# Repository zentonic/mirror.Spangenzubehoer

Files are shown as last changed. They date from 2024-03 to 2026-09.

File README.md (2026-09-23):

# Spangenzubehör

---

> https://forgejo.mueller.network/Zentonic/Spangenzubehoer.git 
> 
> Mirror: https://github.com/zentonic/mirror.Spangenzubehoer.git

---

> License: cc-by-sa-4.0 Author: holm / Christian Müller (https://mueller.network)

3D Druck Vorlage für ein Zubehördöschen mit Schiebedeckel.

Platz für
* Interdentalbürstchen
* frische Gummiringe
* Zahnspangenwachs
* Selbstklebende Spiegelfolie in einer Aussparung im Deckel

[STL-Download](STL/)

## Schiebedeckel für eigene Formen

Der Schiebedeckel steckt als eigenständige Bibliothek in
[`modules/mod_Schiebebox.scad`](modules/mod_Schiebebox.scad): Rechteck mit
Rundung oder beliebiger 2D-Umriss, Arretierung über einen einstellbaren
Hinterschnitt, Presssitz ohne Spiel (optional `spiel`). Beispiel mit
Kapselform: [`beispiele/Kapsel.scad`](beispiele/Kapsel.scad).

```openscad
include <modules/mod_Schiebebox.scad>;
P = sb_param(laenge=60, breite=25, hoehe=20, wand=2.5, rundung=4,
             deckel_d=3, hinterschnitt=0.4);
difference() { sb_koerper(P); sb_nut(P); }
translate([0, 35, 0]) sb_deckel(P);
```

Die Döschen auf [Mastodon](https://social.saarland/@holm/112083961379337663)

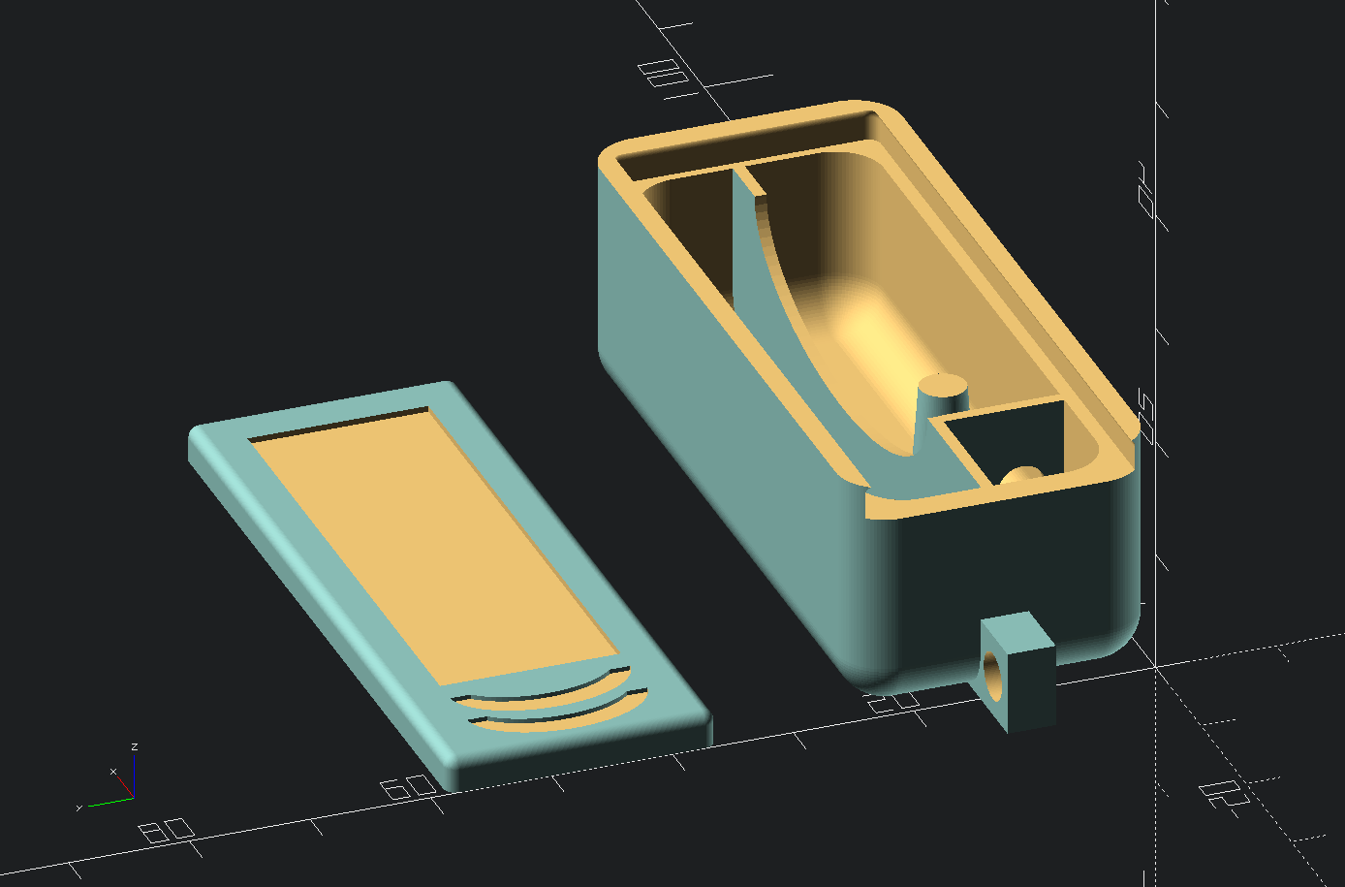
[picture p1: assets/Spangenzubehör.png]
Preview Vorschau


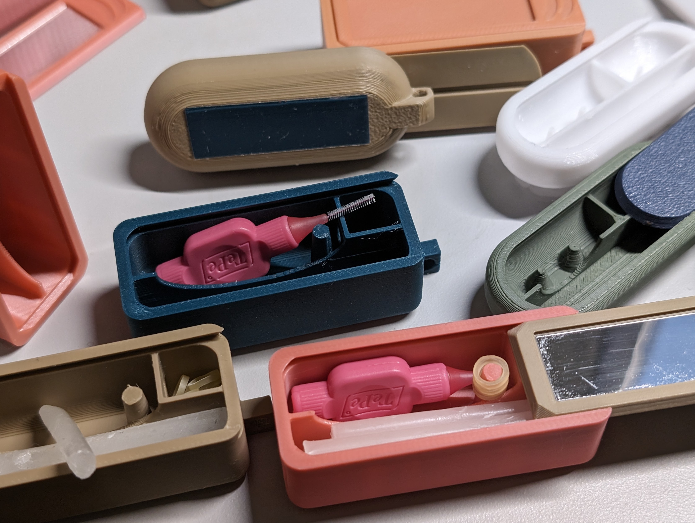
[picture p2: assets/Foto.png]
Foto Foto der Entwicklungsstufen


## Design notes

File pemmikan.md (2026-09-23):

# 🤖🥩 OpenSCAD: Spangenzubehör-Döschen mit Schiebedeckel
> Stand: 2026-09-24 01:10 — Claude.ai via Claude Code (CLI)

## STAND

ROLLE: v00 auf Opus, thinking an

- PCR 2026-09-24 01:10: Pemmikan aktuell, Issues #6–#9 und #11 geschlossen. Release-Schritt offen: `~/bin/release` würde `v2.0.0-rc.3` erzeugen (v-Präfix, ohne cliff.toml, Inhalt nur Doku seit rc.2)
- `main` = `fcb2c0d`, Tag `2.0.0-rc.2` (signiert), Forgejo-Release als Vorabversion mit STL
- **Nächster Schritt (Holm, „morgen")**: Testdruck rc.2 → bei Erfolg PCR/Release **2.0.0 final** — [#10](https://forgejo.mueller.network/Zentonic/Spangenzubehoer/issues/10)
- Branches bleiben nach Merge stehen (Holm): `fix/6-ki-layoutfix`, `fix/7-hauptsteg-zurueck`, `feat/8-schiebebox`, `feat/9-stl-rc2`
- Kein `dev`-Branch, kein CHANGELOG/cliff.toml: Merges gehen `--no-ff` direkt in `main`

## Funktion der Geometrie (Holm 2026-09-23) — Funktionsmaße, keine Kosmetik

| Teil | Funktion | Maß |
|---|---|---|
| Langes Fach (y > Hauptsteg) | Wachsstreifen, Einheitsgröße | **9,0 mm Passmaß** |
| Kurzes Fach (y < Hauptsteg, x > Quersteg) | Griff Interdentalbürste (TePe Original Pink ISO 0) | 10 mm, **bewusst lose** |
| Loch Ø4 im Quersteg | Bürstenspitze ragt in die kleine Kammer, Konus ragt ins Loch | – |
| Kleine Kammer | Zahnspangengummis | – |
| Kegel „Zyl gebraucht" | Abstreifsteg für gebrauchte Gummis (z. B. beim Essen) | Fuß bündig zur Stegseite |
| Deckelmulde | Spiegelklebefolie (Amazon) | 0,5 mm tief |
| Deckel | **Presssitz ohne Spiel**: robustes Schieben, Arretieren durch flächigen Druck | – |

TePe-Bürste, aus Fotos geschätzt (Referenz Dose + Produktbild): Länge ≈ 46 mm, Platte ≈ 13 × 16 mm, Kragen Ø ≈ 7 mm.

## Schiebedeckel-Mechanik (`modules/mod_Schiebebox.scad`, #8)

- Deckel: Platte `deckel_d` mit oben gerundeten Kanten `kante_r`, liegt auf einer Auflage `nut_tiefe` in den Seitenwänden
- Arretierung: Nutoberkante = Rand + `ueberstand`, `ueberstand = kante_r − sqrt(kante_r² − (kante_r − hinterschnitt)²)`; der Rand greift um `hinterschnitt` über die Kantenrundung
- Spangendose: `deckel_d=3`, `kante_r=1`, `hinterschnitt=0.4` (→ Überstand 0,2), `nut_tiefe = wand − rundung/3` und `rest_ende = 0.7·wand` (bewährte Presssitzwerte)
- Umriss: Rechteck oder 2D-Kind (`beispiele/Kapsel.scad`). Bei runden Enden läuft die Wand am Öffnungsende spitz aus → `sb_restwand()` markiert das
- Die alte Rechnung (bis rc.1) passte nur zufällig: Hinterschnitt verschwand bei Deckelstärke +0,5, Nut fest 2,5 unter Rand, Breite an `rundung/3`, Restwand am Nutende ≈ 0,9 mm

## Parameter (Customizer / `Spangenzubehör.json`)

- `wandstaerke` = reale Wanddicke (2,5), intern `wall = 2·wandstaerke`
- `deckelstaerke` = reale Deckeldicke (3); bis rc.1 bedeutete der Wert die Platte ohne Wölbung (2)
- Sätze: „Standardwerte des Designs" (= `.scad`-Defaults, STL-Grundlage) und „Variante 75 mm"

## Verlauf

| Issue | Inhalt |
|---|---|
| #6 | Layoutprüfung + Parametrierung (Halter, Stege, Kegel, Deckellänge, JSON) |
| #7 | Hauptsteg zurück auf 10/9 (Zentrierung in #6 war Fehlurteil) |
| #8 | Bibliothek `mod_Schiebebox`, Spangendose darauf umgestellt |
| #9 | STL `2.0.0-rc.2` |

## Offen

- [#10](https://forgejo.mueller.network/Zentonic/Spangenzubehoer/issues/10) Testdruck → 2.0.0 final
- Alte lokale Arbeitskopie mit Branch `Deckelkram`, Stash und Klammer-Fix-Commit (Details im Flotten-Inventar): unangetastet, Holm entscheidet
- Prüfwerkzeug: OpenSCAD per `nix shell nixpkgs#openscad-unstable` (2026.02, `--backend=manifold`)

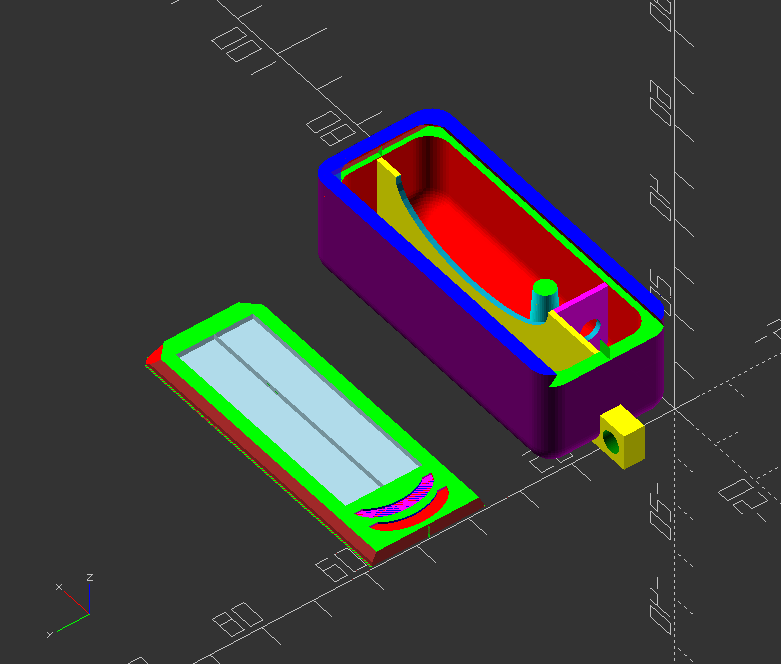
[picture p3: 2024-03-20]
assets/Preview.png

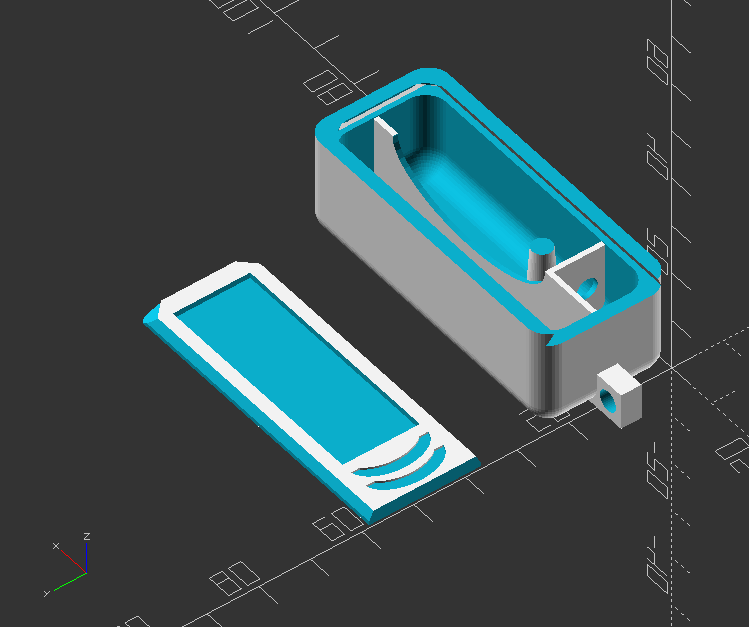
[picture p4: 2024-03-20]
assets/Preview-Render.png

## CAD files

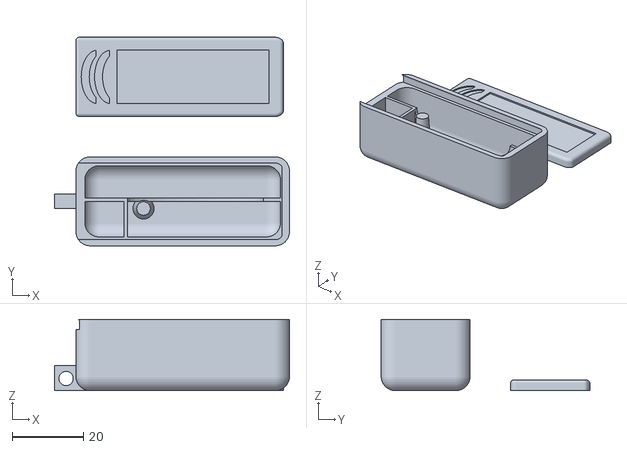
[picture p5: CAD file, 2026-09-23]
STL/Spangenzubehör-2.0.0-rc.2.stl
66.0 x 58.6 x 20.0

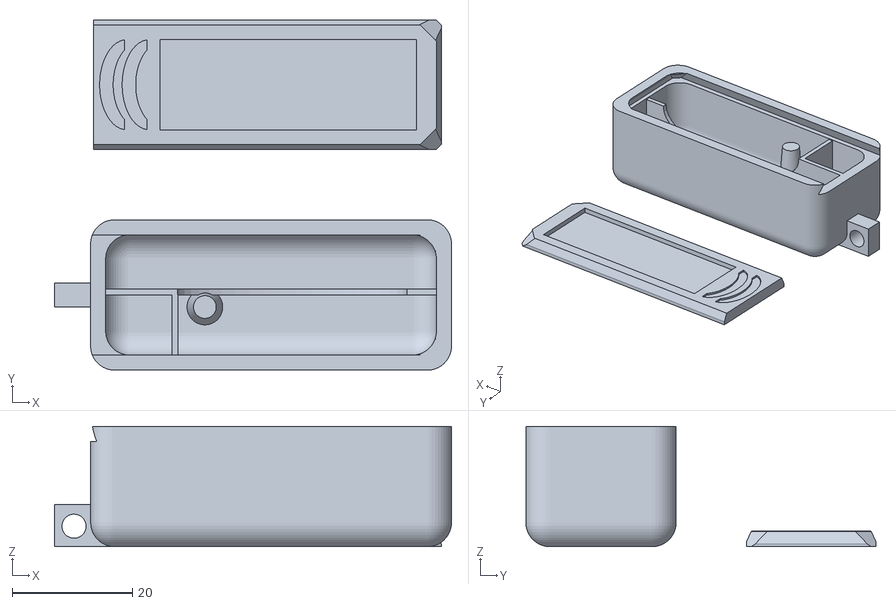
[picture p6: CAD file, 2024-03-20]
STL/Spangenzubehör_v1.1.stl
66.0 x 58.2 x 20.0

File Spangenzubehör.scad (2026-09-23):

// License: cc-by-sa-4.0 Author: holm / Christian Müller (https://mueller.network)

// Definitions
// *********************
//

detailgrad = 40;
wandstaerke = 2.5;    // reale Wanddicke der Box
deckelstaerke = 3;    // reale Dicke des Schiebedeckels
hinterschnitt = 0.4;  // wie weit der Rand über den Deckel greift (Arretierung)
rundung = 4;
vollebreite = 60;
vollelaenge = 25;
vollehoehe = 20;

// Prozessvariablen
{
  wall = 2*wandstaerke;
  $fn = detailgrad;
  // Deckel und Nut haben bewusst kein Spiel: Presssitz für robustes
  // Schieben und Arretieren durch flächigen Druck. Nuttiefe und Restwand
  // am Ende sind die bewährten Werte der Spangendose.
  P = sb_param(laenge=vollebreite, breite=vollelaenge, hoehe=vollehoehe,
               wand=wandstaerke, rundung=rundung,
               deckel_d=deckelstaerke, kante_r=1, hinterschnitt=hinterschnitt,
               nut_tiefe=wandstaerke-rundung/3, rest_ende=0.7*wandstaerke);
  hoehe = vollehoehe-rundung;
}

include <modules/mod_Schiebebox.scad>;
include <modules/mod_Deckel.scad>;
include <modules/mod_Box.scad>;

difference() {
  Box();
  sb_nut(P);
}

scale([1,0.999,0.999])
translate([0, vollelaenge+10, 0]) {
  Deckel(griff=true,spiegel=true);
}

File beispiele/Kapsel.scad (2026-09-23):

// License: cc-by-sa-4.0 Author: holm / Christian Müller (https://mueller.network)
//
// Beispiel: Schiebebox mit Kapsel-Umriss (Halbkreise an beiden Enden)

laenge = 70;
breite = 24;
hoehe = 16;
wand = 2;
rundung = 3;
deckel_d = 2.6;
hinterschnitt = 0.4;
restwand_zeigen = false;

$fn = 48;
P = sb_param(laenge=laenge, breite=breite, hoehe=hoehe, wand=wand,
             rundung=rundung, deckel_d=deckel_d, hinterschnitt=hinterschnitt);

include <../modules/mod_Schiebebox.scad>;

module kapsel() {
  hull() {
    translate([breite/2, breite/2]) circle(d=breite);
    translate([laenge-breite/2, breite/2]) circle(d=breite);
  }
}

difference() {
  sb_koerper(P) kapsel();
  sb_nut(P) kapsel();
}

translate([0, breite+8, 0]) sb_deckel(P) kapsel();

if (restwand_zeigen) translate([0,0,-2]) sb_restwand(P) kapsel();

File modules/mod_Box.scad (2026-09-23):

// License: cc-by-sa-4.0 Author: holm / Christian Müller (https://mueller.network)

module Box() {
  // Innenmaße (global): Wand und Boden sind wall/2 dick
  innen = wall/2;
  stegdicke = 1;
  stegfuss = innen-0.5;                  // Stege stecken 0.5 im Boden
  // Hauptsteg bewusst aussermittig: Wachsfach (Passmass) schmaler als Buerstenfach
  steg_y = vollelaenge*0.5;
  quersteg_x = innen+11;
  zyl_x = quersteg_x+5.5;

  // Box (Schiebebox-Körper, Nut wird im Hauptfile abgezogen)
  color("purple",0.7)
  sb_koerper(P);

  // Halter mit Öse, steht auf z=0
  difference() {
    translate([-1,vollelaenge/2,3.5])
    color("yellow")
    cube([10,4,7],true);
    translate([-2.75,vollelaenge/2,3.4])
    rotate([270,0,0])
    color("green")
    cylinder(h=7,d=4,center=true);
    sb_innenraum(P);
  }
  
  // Hauptsteg
  difference() {
    //Hauptsteg: beidseitig 0.1 in der Wand
    translate([innen-0.1,steg_y,stegfuss]) 
    color("yellow")
    cube([vollebreite-wall+0.2,stegdicke,hoehe-0.7]);
    
    // Durchgriff
    translate([vollebreite/2+3.55,vollelaenge*0.5+2.5,vollehoehe-3])
    rotate([90,0,0])
    scale([2.25,1])
    cylinder(h=5,r=8.5);    
  }
  // Quersteg 1
  difference() {
    translate([quersteg_x,innen,stegfuss]) 
    color("magenta")
    cube([1,(vollelaenge-wall)/2+0.1,hoehe-0.7]); 
    
    // Durchgriff
    translate([quersteg_x-2.5,innen+3.5,vollehoehe/2])
    rotate([0,90,0])
    cylinder(h=4,r=2);}
      
  // Zyl gebraucht 2/2: Fuss bündig mit der Stegseite zum Wachsfach
  translate([zyl_x,steg_y+stegdicke-3,stegfuss]) 
    color("cyan")
    cylinder(h=vollehoehe-1.2-stegfuss, r1=3, r2=1.8);
}

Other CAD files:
STL/Spangenzubehör-2.0.0-rc.1.stl
modules/mod_Deckel.scad
modules/mod_Schiebebox.scad

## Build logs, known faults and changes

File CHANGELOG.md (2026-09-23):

# Changelog

Alle nennenswerten Änderungen an diesem Projekt werden hier dokumentiert.

Format orientiert sich an [Keep a Changelog](https://keepachangelog.com/de/1.1.0/),

Versionen folgen [Semantic Versioning](https://semver.org/lang/de/).

## [unreleased]

### 📝 Documentation

- Pemmikan.md angelegt (Stand nach rc.2) ([`617adc3`])
- Pemmikan PCR-Stand ([`2e5644f`])

## [2.0.0-rc.2] – 2026-09-23

### ✨ Added

- Schiebedeckel als parametrierbare Bibliothek mod_Schiebebox ([`6d0bd89`])

### 🐛 Fixed

- Dosenlayout parametrierbar, JSON-Satz, Steg mittig, Spiegelmulde ([`ef58b4a`])
- Hauptsteg zurück auf 10/9 mm, Abstreifkegel bündig ([`c01b160`])

## [2.0.0-rc.1] – 2024-03-21

<!-- generated by git-cliff -->

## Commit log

2024-03-20 Split in Submodule
    [Spangenzubehör.scad]
2024-03-20 Fotos und Beschreibung
2024-03-20 TODO: Parametrierbarkeit
    [Spangenzubehör.scad]
2024-03-21 License: cc-by-sa-4.0 Author: holm / Christian Müller (https://mueller.network)
    [Spangenzubehör.scad, mod_Box.scad, mod_Deckel.scad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]
2024-03-21 Deckel konvex
    [Spangenzubehör-2.0.0-rc.1.stl, Spangenzubehör.scad, Spangenzubehör_v1.1.stl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]
2025-02-12 Low Quality
    [Spangenzubehör.scad]
2026-09-23 fix: Dosenlayout parametrierbar, JSON-Satz, Steg mittig, Spiegelmulde
    - Halter, Durchgriffe, Quersteg, Zylinderhoehe, Deckellaenge an Parameter
    gebunden; Standardgeometrie unveraendert (ausser Hauptsteg)
    - wandstaerke = reale Wanddicke (Default 2.5, intern wall = 2*wandstaerke)
    - JSON "Standardwerte" = .scad-Defaults; Altsatz als "Variante 75 mm"
    - Hauptsteg mittig, beidseitig 0.1 in der Wand
    - Spiegel- und Griffmulde relativ zur Deckeloberkante
    - toter kante-Zweig entfernt, koplanaren Kantenschnitt verlaengert
    - Presssitz des Deckels bewusst, als Kommentar dokumentiert
    Fixes #6
    [Spangenzubehör.scad, mod_Box.scad, mod_Deckel.scad]
2026-09-23 fix: Hauptsteg zurück auf 10/9 mm, Abstreifkegel bündig
    Die Aussermittigkeit ist Funktion: Wachsfach (9 mm) ist Passmass fuer
    Wachsstreifen, Buerstenfach (10 mm) bewusst lose. #6 hatte den Steg
    zentriert; dadurch ragte der Kegelfuss 0.5 mm ins Wachsfach.
    - steg_y = vollelaenge/2 wie im Original, 0.1 Wandueberlappung bleibt
    - Kegelmitte an Stegseite gebunden (steg_y + stegdicke - r1)
    - Standardgeometrie volumengleich zum Original vor #6
    Fixes #7
    [mod_Box.scad]
2026-09-23 feat: Schiebedeckel als parametrierbare Bibliothek mod_Schiebebox
    Neue Bibliothek fuer Boxen mit einrastendem Schiebedeckel, Umriss als
    Rechteck mit Rundung oder beliebiges 2D-Kind (Beispiel Kapsel).
    - Arretierung explizit: Nutoberkante = Rand + ueberstand, aus
    `hinterschnitt` und `kante_r` exakt berechnet (vorher zufaellig 0.4)
    - Nutlage aus deckel_d abgeleitet statt fest 2.5 unter dem Rand
    - Nutbreite aus wand/nut_tiefe statt rundung/3
    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
    [Kapsel.scad, Spangenzubehör.scad, mod_Box.scad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]
2026-09-23 build: STL 2.0.0-rc.2 aus aktuellem Stand erzeugt
    Standardwerte des Designs, OpenSCAD 2026.02 (manifold), binaer.
    Enthaelt #6, #7 und #8. Vorhandene STLs unveraendert.
    Fixes #9
    [Spangenzubehör-2.0.0-rc.2.stl]
